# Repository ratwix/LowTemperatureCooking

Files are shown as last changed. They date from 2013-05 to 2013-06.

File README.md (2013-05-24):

LowTemperatureCooking
=====================

Low temperature cooking

Target of this project is to create a Low temperature cooker based on Arduino Teensy 3.

Goal is to heat water to a specific temperature just perfect for cooking the specific dish.
A big amount a pre-set temperature are embeded.

All the temperatures and time cooking comes from "Modernist Cuisine" book.

Main element :
- Teensy3 for main program
- Nokia 5110 for the screen
- DS18B20 for temperature checking
- Rotary encoder to navigate throw menu
- Two button
-- Back / Reset Timer
-- Menu / Validate
- 220V Heat resistor

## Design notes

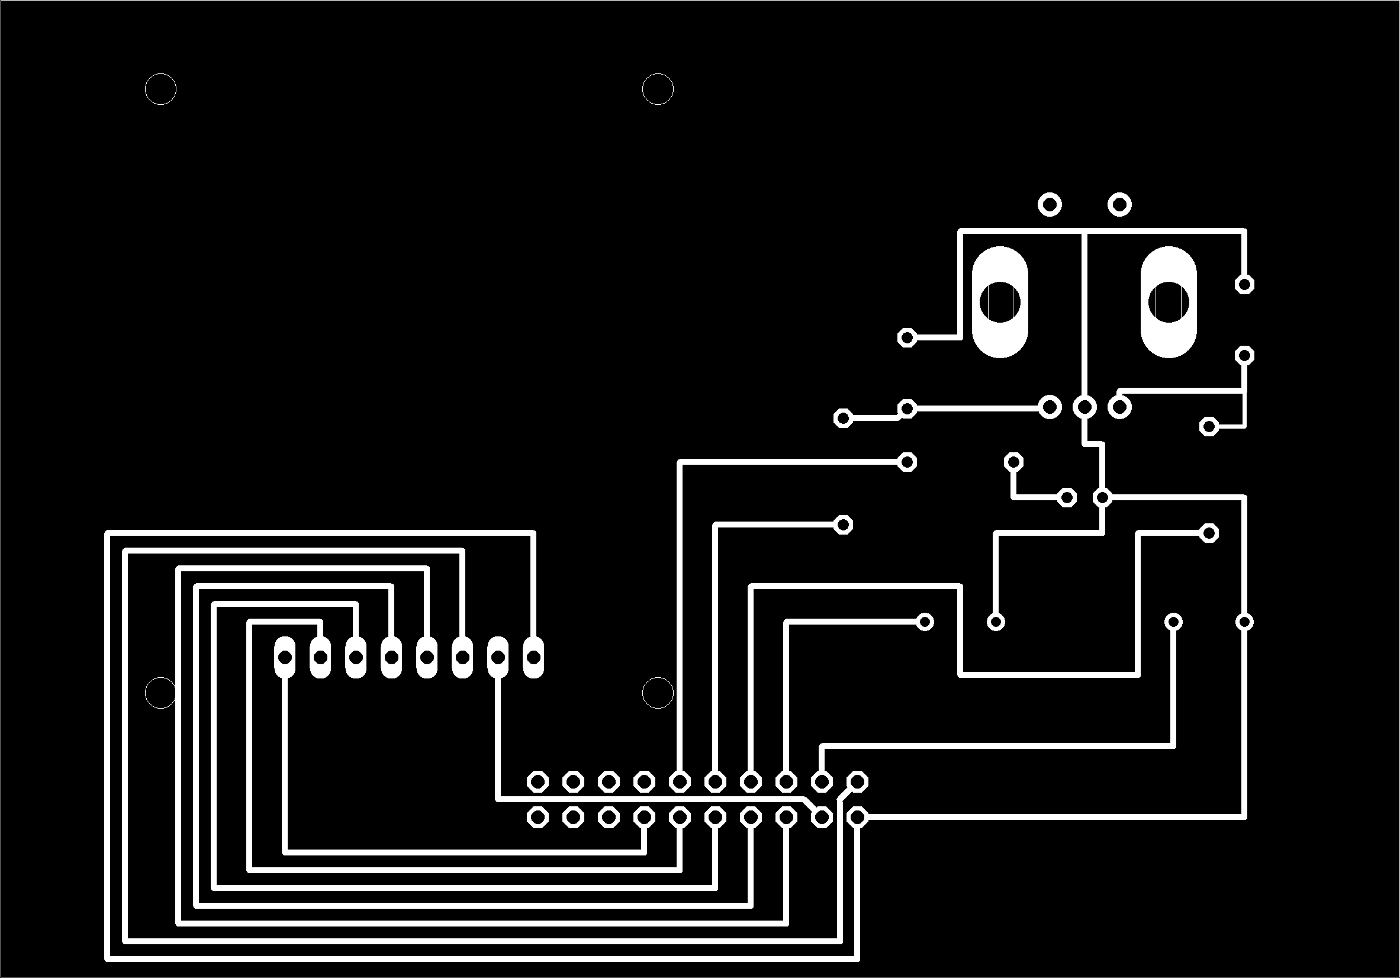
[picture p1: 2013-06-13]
Schematic/CoolCook/board2.png

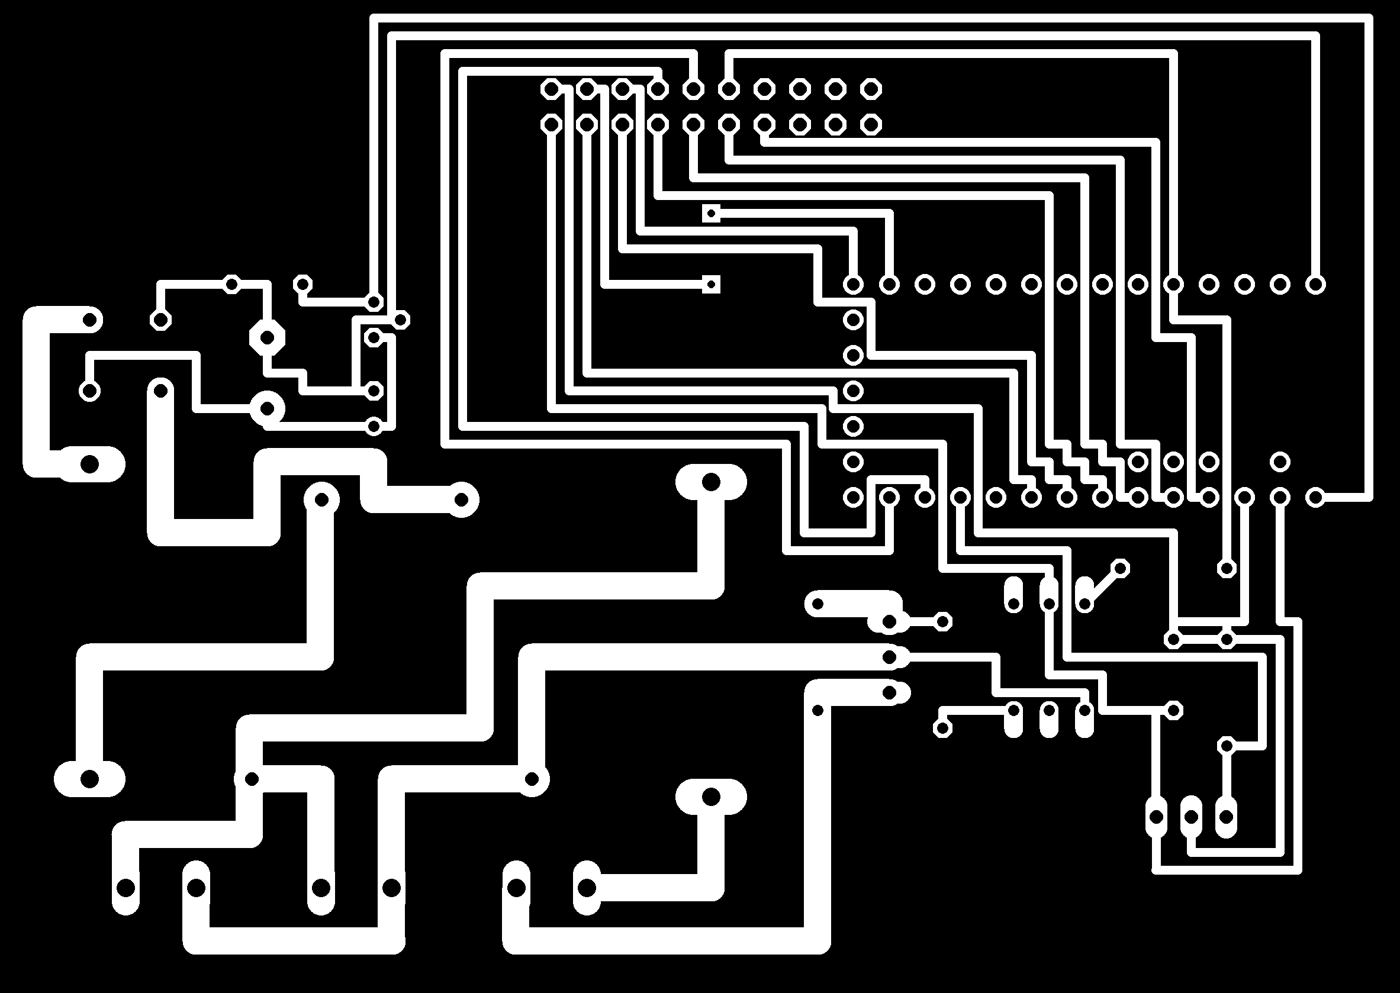
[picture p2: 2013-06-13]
Schematic/CoolCook/board1.png

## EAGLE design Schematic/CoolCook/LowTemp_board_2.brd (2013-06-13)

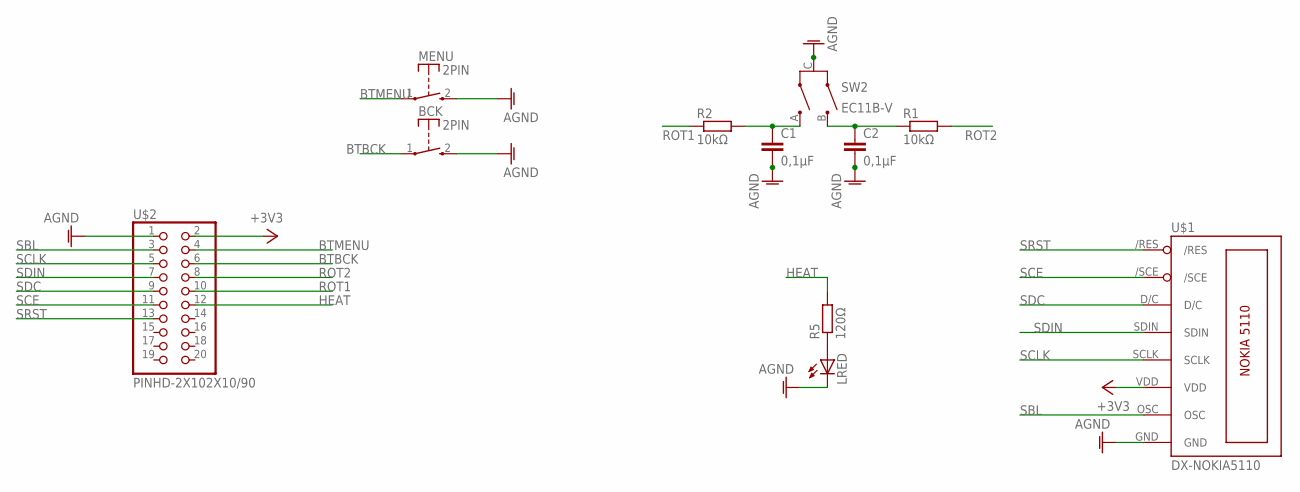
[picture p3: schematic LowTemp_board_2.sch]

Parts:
BCK: 2PIN
C1, C2: 0,1µF; C050-025X075
LRED: LED5MM
MENU: 2PIN
R1, R2: 10kΩ; 0207/7
R5: 120Ω; 0207/7
SW2: EC11B-V
U$1: DX-NOKIA5110
U$2: PINHD-2X102X10/90; 2X10/90

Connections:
+3V3: U$1.VDD, U$2.2
AGND: BCK.2 (S), C1.2, C2.2, LRED.K (C), MENU.2 (S), SW2.C, U$1.GND, U$2.1
BTBCK: BCK.1, U$2.6
BTMENU: MENU.1, U$2.4
HEAT: R5.2, U$2.12
unnamed: C1.1, R2.2, SW2.A
unnamed: C2.1, R1.1, SW2.B
unnamed: LRED.A, R5.1
ROT1: R2.1, U$2.10
ROT2: R1.2, U$2.8
SBL: U$1.OSC, U$2.3
SCE: U$1./SCE, U$2.11
SCLK: U$1.SCLK, U$2.5
SDC: U$1.D/C, U$2.9
SDIN: U$1.SDIN, U$2.7
SRST: U$1./RES, U$2.13

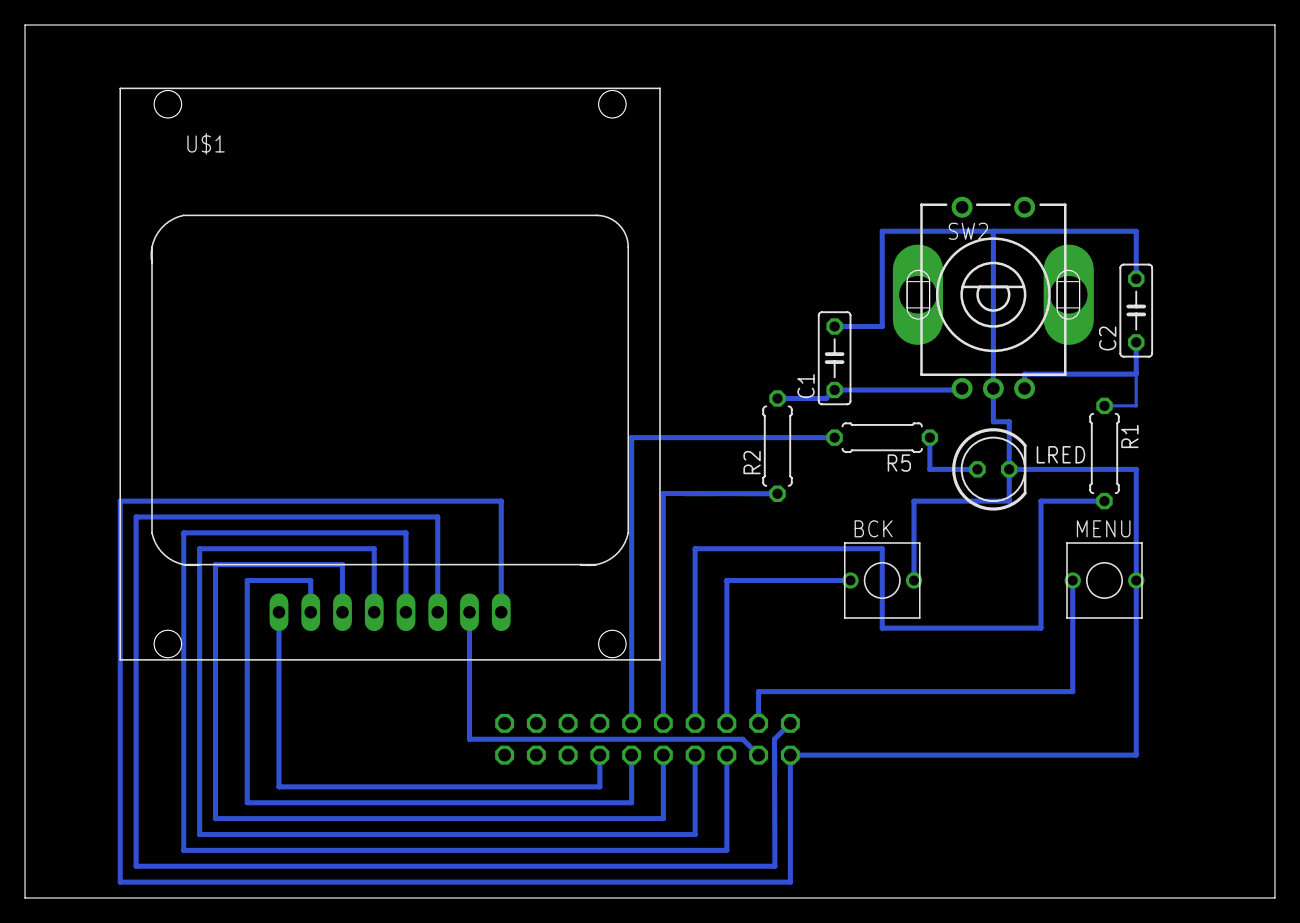
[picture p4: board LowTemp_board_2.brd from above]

Board: 2 copper layers, 100.0 x 69.8 mm, 11 parts (1 on the bottom side), 16 nets.

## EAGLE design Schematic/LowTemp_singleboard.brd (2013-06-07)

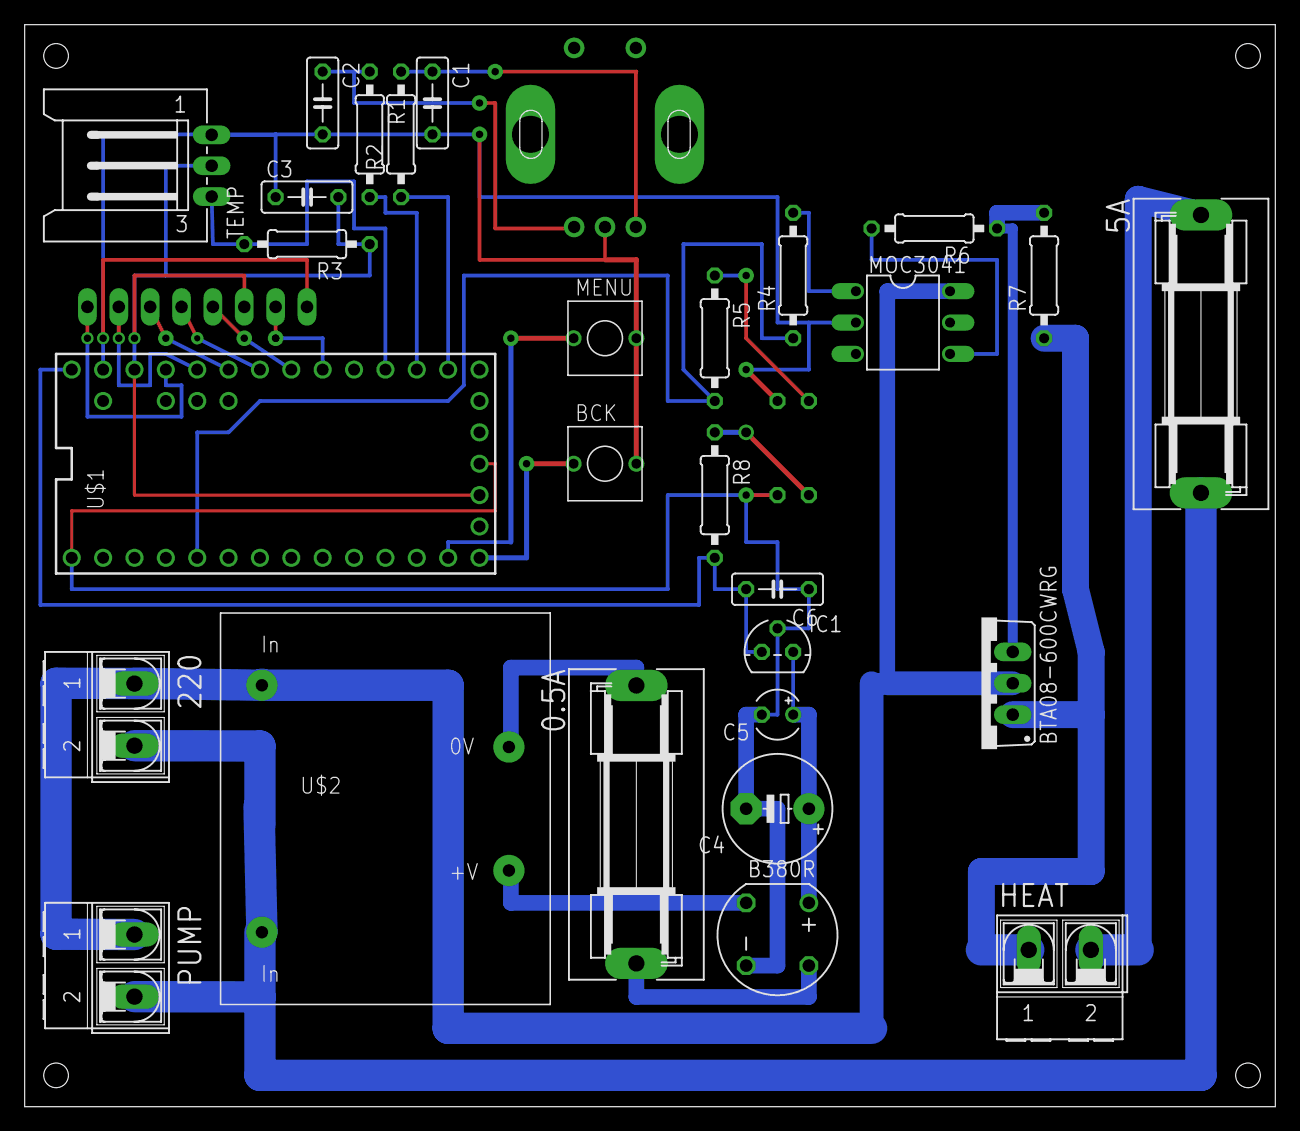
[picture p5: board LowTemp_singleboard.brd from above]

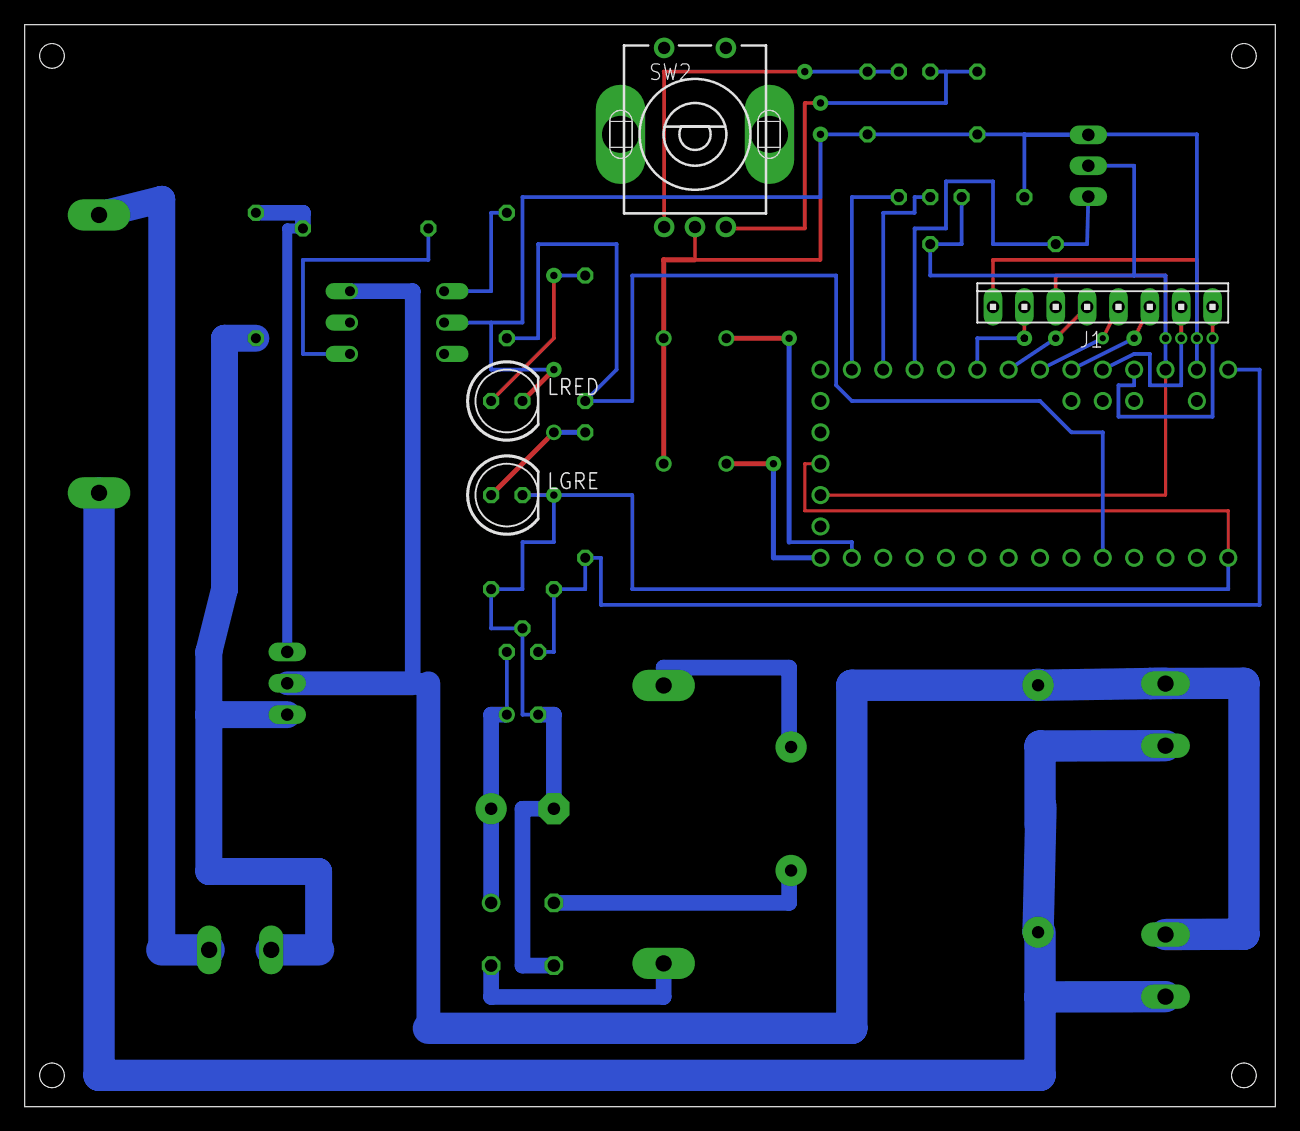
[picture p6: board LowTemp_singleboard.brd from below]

Board: 2 copper layers, 101.3 x 87.6 mm, 32 parts (4 on the bottom side), 31 nets.

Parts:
0.5A, 5A: SH22,5A
220: AK500/2-H
B380R: RB1A
BCK: 2PIN
BTA08-600CWRG: BT138-V; TO220BV
C1, C2, C3, C6: 0,1µF; C050-025X075
C4: 470µF; E5-8,5
C5: 3,3µF; TT2D4
HEAT: AK500/2-H
IC1: 7805L; TO92
J1: SCREEN; 10X08MTA
LGRE: LED5MM
LRED: LED5MM
MENU: 2PIN
MOC3041: MOC3021M; DIL06
PUMP: AK500/2-H
R1, R2: 10kΩ; 0207/10
R3: 47kΩ; 0207/10
R4: 130Ω; 0207/10
R5: 120Ω; 0207/10
R6: 360Ω; 0207/10
R7: 63Ω; 0207/10
R8: 330Ω; 0207/10
SW2: EC11B-V
TEMP: L03P
U$1: TEENSY_3.0+4
U$2: 1

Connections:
220VA: BTA08-600CWRG.T2, MOC3041.6, PUMP.1, U$2.1
220VC: 5A.2, 220.2, PUMP.2, U$2.5
+3V3: C3.2, J1.6, R3.1, TEMP.2, U$1.3.3V, U$1.3.3V1
+5V: C6.2, IC1.1, R8.2, U$1.VIN
AGND: BCK.2, C1.2, C2.2, C3.1, J1.8, LRED.K, MENU.2, MOC3041.2, SW2.C, TEMP.1, U$1.AGND
BTBCK: BCK.1, U$1.12
BTMENU: MENU.1, U$1.11
GND: B380R.-, C4.-, C5.-, C6.1, IC1.2, LGRE.K, U$1.GND, U$1.GND1
HEAT: R4.1, R5.2, U$1.3
unnamed: C1.1, R2.2, SW2.A
unnamed: C2.1, R1.1, SW2.B
unnamed: MOC3041.1, R4.2
unnamed: LRED.A, R5.1
unnamed: MOC3041.4, R6.2
unnamed: BTA08-600CWRG.G, R6.1, R7.2
unnamed: 0.5A.1, U$2.9
unnamed: BTA08-600CWRG.T1, HEAT.1, R7.1
unnamed: 5A.1, HEAT.2
unnamed: B380R.AC2, U$2.7
unnamed: 0.5A.2, B380R.AC1
unnamed: B380R.+, C4.+, C5.+, IC1.3
unnamed: LGRE.A, R8.1
ROT1: R2.1, U$1.14/A0
ROT2: R1.2, U$1.15/A1
SBL: J1.7, U$1.18/A4
SCE: J1.2, U$1.22/A8
SCLK: J1.5, U$1.19/A5
SDC: J1.3, U$1.21/A7
SDIN: J1.4, U$1.20/A6
SRST: J1.1, U$1.23/A9
TEMP: R3.2, TEMP.3, U$1.16/A2

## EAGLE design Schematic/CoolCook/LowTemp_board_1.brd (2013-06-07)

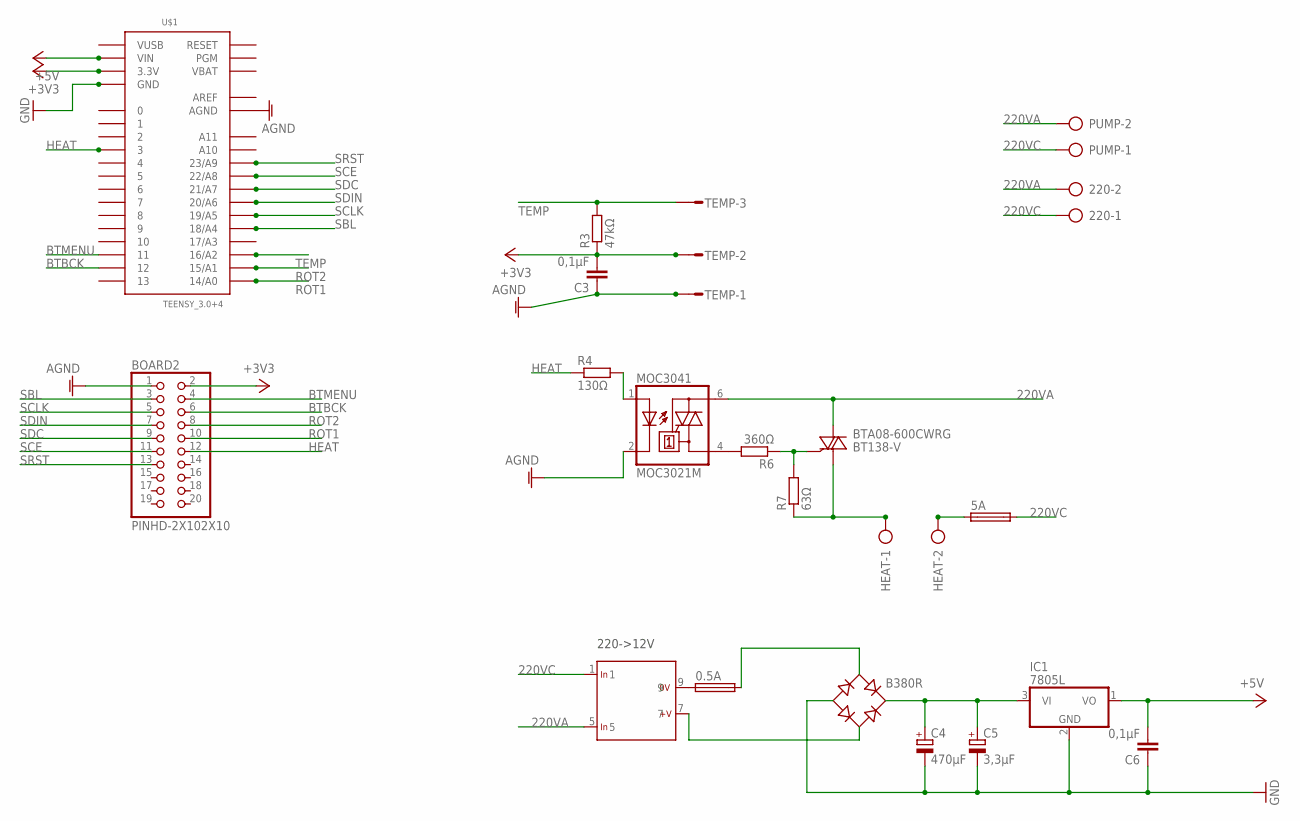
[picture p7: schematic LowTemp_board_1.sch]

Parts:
0.5A, 5A: SH22,5A
220: AK500/2-H
220->12V: SINGLE; 1
B380R: RB1A
BOARD2: PINHD-2X102X10; 2X10
BTA08-600CWRG: BT138-V; TO220BV
C3, C6: 0,1µF; C050-025X075
C4: 470µF; E5-8,5
C5: 3,3µF; TT2D4
HEAT: AK500/2-H
IC1: 7805L; TO92
MOC3041: MOC3021M; DIL06
PUMP: AK500/2-H
R3: 47kΩ; 0207/7
R4: 130Ω; 0207/7
R6: 360Ω; 0207/7
R7: 63Ω; 0207/7
TEMP: S03P
U$1: TEENSY_3.0+4

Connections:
220VA: 220.2, 220->12V.5, BTA08-600CWRG.T2 (A2), MOC3041.6 (A2), PUMP.2
220VC: 5A.2, 220.1, 220->12V.1, PUMP.1
+3V3: BOARD2.2, C3.2, R3.1, TEMP.2, U$1.3.3V, U$1.3.3V1 (3.3V)
+5V: C6.2, IC1.1 (VO), U$1.VIN
AGND: BOARD2.1, C3.1, MOC3041.2 (C), TEMP.1, U$1.AGND
AREF: U$1.AREF
BTBCK: BOARD2.6, U$1.12
BTMENU: BOARD2.4, U$1.11
GND: B380R.-, C4.-, C5.-, C6.1, IC1.2 (GND), U$1.GND, U$1.GND1 (GND)
HEAT: BOARD2.12, R4.1, U$1.3
unnamed: MOC3041.1 (A), R4.2
unnamed: MOC3041.4 (A1), R6.2
unnamed: BTA08-600CWRG.G, R6.1, R7.2
unnamed: 0.5A.1, 220->12V.9
unnamed: BTA08-600CWRG.T1 (A1), HEAT.1, R7.1
unnamed: 5A.1, HEAT.2
unnamed: 220->12V.7, B380R.AC2
unnamed: 0.5A.2, B380R.AC1
unnamed: B380R.+, C4.+, C5.+, IC1.3 (VI)
ROT1: BOARD2.10, U$1.14/A0
ROT2: BOARD2.8, U$1.15/A1
SBL: BOARD2.3, U$1.18/A4
SCE: BOARD2.11, U$1.22/A8
SCLK: BOARD2.5, U$1.19/A5
SDC: BOARD2.9, U$1.21/A7
SDIN: BOARD2.7, U$1.20/A6
SRST: BOARD2.13, U$1.23/A9
TEMP: R3.2, TEMP.3, U$1.16/A2
VBAT: U$1.VBAT
VUSB: U$1.VUSB

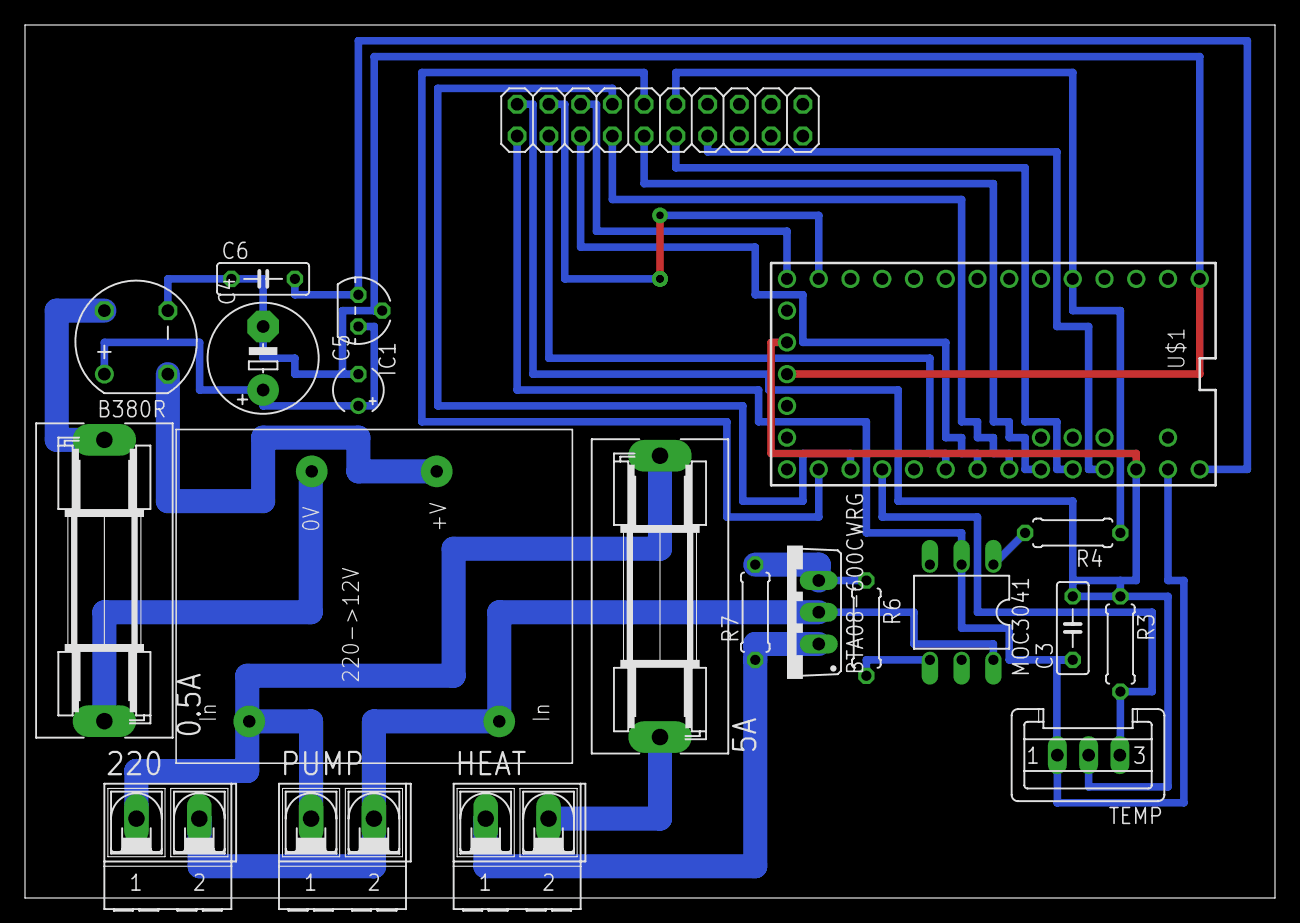
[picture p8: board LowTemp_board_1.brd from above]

Board: 2 copper layers, 100.0 x 69.8 mm, 21 parts (0 on the bottom side), 27 nets.

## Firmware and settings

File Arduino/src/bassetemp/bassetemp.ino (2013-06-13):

#include <OneWire.h> // Inclusion de la librairie OneWire
#include <Time.h>
#define ENCODER_OPTIMIZE_INTERRUPTS //Rotary optimization
#include <Encoder.h> //Rotary encoder
#include <Bounce.h> //Button management
#include <Adafruit_GFX.h>
#include <Adafruit_PCD8544.h>

#include "logo.h"
#include "menu.h"

/**
  *  Ecran
  */

#define DELAY_REFRESH_TEMP  100

#define PIN_SCREEN_LED    18
#define PIN_SCREEN_SCLK   19
#define PIN_SCREEN_DIN    20
#define PIN_SCREEN_DC     21
#define PIN_SCREEN_CS     22
#define PIN_SCREEN_RST    23
#define DELAY_REFRESH_SCREEN  100
#define DELAY_MENU_TIMEOUT    20000
#define DELAY_SCROLL          200
#define DELAY_SCROLL_DELAY    4

Adafruit_PCD8544 display = Adafruit_PCD8544(PIN_SCREEN_SCLK, PIN_SCREEN_DIN, PIN_SCREEN_DC, PIN_SCREEN_CS, PIN_SCREEN_RST);

elapsedMillis time_refreshTemperature;
elapsedMillis time_refreshScreen;
elapsedMillis time_menuTimeout;
elapsedMillis time_menuScroll;

int scroll_poss = 0;
int scroll_max = 0;

/**
  * Temperature
  */

#define DS18B20     0x28     // Adresse 1-Wire du DS18B20
#define PIN_DS18B20 16       // Pin used for temp 1-Wire
#define PIN_HEAT    3        // Pin connected to HEAT system (PWM)

OneWire ds(PIN_DS18B20);

float   g_target_temp   = 40.0;
float   g_current_temp  = 12.4;

boolean  g_heat = false; //Heat if true

/**
  * Chronometre
  */
  
time_t g_chrono_time = now();

/**
  * Rotary Encoder
  */
#define PIN_ROTARY1         15
#define PIN_ROTARY2         14
#define ENCODER_STEP        0.1 //Add 0.1° each step
#define ENCODER_MENU_STEP   2   //Increment menu each 2 tick
Encoder g_rotaryEncoder(PIN_ROTARY1, PIN_ROTARY2);

/**
  * Button
  */
  
#define  PIN_BUTTON_RESET_TIMER  12
#define  PIN_BUTTON_MENU         11

Bounce buttonResetTimer = Bounce(PIN_BUTTON_RESET_TIMER, 10);
Bounce buttonMenu = Bounce(PIN_BUTTON_MENU, 10);

/************************************************************************************
  ******
  ******  Main loop
  ******
  ***********************************************************************************/

void setup()   {
  Serial.begin(9600);
  
  pinMode(PIN_HEAT, OUTPUT);
  
  pinMode(PIN_BUTTON_RESET_TIMER, INPUT_PULLUP);
  pinMode(PIN_BUTTON_MENU, INPUT_PULLUP);

  //Switch screen led on
  pinMode(PIN_SCREEN_LED, OUTPUT);
  
  digitalWrite(PIN_SCREEN_LED, HIGH);
  
  //Initialise Screen
  display.begin();
  display.setContrast(51);

  //display.display(); // show splashscreen
  display.clearDisplay();
  //display.command(PCD8544_DISPLAYCONTROL | PCD8544_DISPLAYNORMAL);
  display.drawBitmap(0, 0, logo, logox, logoy, BLACK);
  display.display();
  delay(3000);
  display.clearDisplay();   // clears the screen and buffer
  display.setTextWrap(false); // Do not wrap text (for scrolling effect)
  
  g_rotaryEncoder.write(0);
  

}

void loop() {
  testControl();
  refreshTemp();
  refreshScreen();
  menuTimeout();
}

/************************************************************************************
  ******
  ******  Control management
  ******
  ***********************************************************************************/

/**
 * Test all controls
 */

void testControl() {
  testButtonReset();
  testButtonMenu();
  readRotaryEncoder();
}

/**
 * Test Reset / Back button
 */

void testButtonReset() {
  if (buttonResetTimer.update()) {
     if (buttonResetTimer.fallingEdge()) {
        time_menuTimeout = 0;
        scroll_poss = DELAY_SCROLL_DELAY;
        if (g_current_menu == 0) {
          g_chrono_time = now();
        } else if (g_current_menu == 1) {
          g_current_menu = 0;
        } else if (g_current_menu == 2) {
          g_current_menu = 1;
        } else if (g_current_menu == 3) {
          g_current_menu = 2;
        } else {
          g_current_menu = 0;
        }
     } 
  }
}

/**
  * Test Menu / Validate button
  */
  
void testButtonMenu() {
  if (buttonMenu.update()) {
     if (buttonMenu.fallingEdge()) {
        time_menuTimeout = 0;
        scroll_poss = DELAY_SCROLL_DELAY;
        if (g_current_menu == 0) {
           init_menu(); //Put current menu item at 0
           g_current_menu = 1; 
        } else if (g_current_menu == 1) { //Goto menu 2
           g_current_menu_2 = 0;
           g_current_menu_3 = 0;
           g_current_menu = 2; 
        } else if (g_current_menu == 2) { //Goto menu 3
           g_current_menu_3 = 0;
           g_current_menu = 3; 
        } else if (g_current_menu == 3) { //Assign temperature
           char tmp = temperature[g_current_menu_1].menu2[g_current_menu_2].menu3[g_current_menu_3].temp;
           if (tmp > 0) {
               g_target_temp = tmp + 1;
           }
           g_current_menu = 0; 
        } else {
           g_current_menu = 0; 
        }
     } 
  }
}

/**
  * Read roatry encoder (left / right
  * If main screen : change target temperature
  * If menu : navigate throw items
  */

void readRotaryEncoder() {
  static int nbTic = 0;
  long newPosition = g_rotaryEncoder.read();
  
  if (newPosition != 0) {
      time_menuTimeout = 0;
      scroll_poss = DELAY_SCROLL_DELAY;
      if (g_current_menu == 0) { //In main screen, directly change temperature
        g_target_temp += newPosition * ENCODER_STEP;
      } else  { //Navigate throw menu
        nbTic += newPosition;
        if (nbTic % ENCODER_MENU_STEP == 0) { //Increment calculator
           if (g_current_menu == 1) {
             int menu_size = get_menu1_size();
             g_current_menu_1 += nbTic > 0 ? 1 : -1; //Increment menu
             if (g_current_menu_1 < 0) { g_current_menu_1 = 0; } //manage menu size
             if (g_current_menu_1 >= menu_size) { g_current_menu_1 = menu_size - 1; }
           } else if (g_current_menu == 2) { 
             int menu_size = get_menu2_size(g_current_menu_1);
             g_current_menu_2 += nbTic > 0 ? 1 : -1; //Increment menu
             if (g_current_menu_2 < 0) { g_current_menu_2 = 0; } //manage menu size
             if (g_current_menu_2 >= menu_size) { g_current_menu_2 = menu_size - 1; }
           } else if (g_current_menu == 3) {
             int menu_size = get_menu3_size(g_current_menu_1, g_current_menu_2);
             g_current_menu_3 += nbTic > 0 ? 1 : -1; //Increment menu
             if (g_current_menu_3 < 0) { g_current_menu_3 = 0; } //manage menu size
             if (g_current_menu_3 >= menu_size) { g_current_menu_3 = menu_size - 1; }
           }
           nbTic = 0; 
        }
      }
      g_rotaryEncoder.write(0);  
  }
}



/************************************************************************************
  ******
  ******  Temperature capture management
  ******
  ***********************************************************************************/

/**
  * Read Temperature.
  * If temperature < target, heat, else stno
  */

void refreshTemp() {
  if (time_refreshTemperature > DELAY_REFRESH_TEMP) {
      time_refreshTemperature -= DELAY_REFRESH_TEMP;
      getTemperature(&g_current_temp);
      if (g_current_temp < g_target_temp) {
        digitalWrite(PIN_HEAT, HIGH);        //TURN HEAT ON
      } else {
        digitalWrite(PIN_HEAT, LOW);         //TURN HEAT OFF
      }
  }
}

/**
  * Get current temperature in Celcius
  */

boolean getTemperature(float *temp){
  byte data[9], addr[8];
  // data : Données lues depuis le scratchpad
  // addr : adresse du module 1-Wire détecté
  

  if (!ds.search(addr)) { // Recherche un module 1-Wire
    ds.reset_search();    // Réinitialise la recherche de module
    return false;         // Retourne une erreur
  }
  
  if (OneWire::crc8(addr, 7) != addr[7]) // Vérifie que l'adresse a été correctement reçue
    return false;                        // Si le message est corrompu on retourne une erreur

  if (addr[0] != DS18B20) // Vérifie qu'il s'agit bien d'un DS18B20
    return false;         // Si ce n'est pas le cas on retourne une erreur

  ds.reset();             // On reset le bus 1-Wire
  ds.select(addr);        // On sélectionne le DS18B20
  
  ds.write(0x44, 1);      // On lance une prise de mesure de température
  //delay(400);             // Et on attend la fin de la mesure
  
  ds.reset();             // On reset le bus 1-Wire
  ds.select(addr);        // On sélectionne le DS18B20
  ds.write(0xBE);         // On envoie une demande de lecture du scratchpad

  for (byte i = 0; i < 9; i++) // On lit le scratchpad
    data[i] = ds.read();       // Et on stock les octets reçus
  
  // Calcul de la température en degré Celsius
  *temp = ((data[1] << 8) | data[0]) * 0.0625; 
  
  // Pas d'erreur
  return true;
}

/************************************************************************************
  ******
  ******  SCREEN MANAGEMENT
  ******
  ***********************************************************************************/

/**
 * Choose what to display on screen
 */

void refreshScreen() {
  menuScroll(); 
  if (time_refreshScreen > DELAY_REFRESH_SCREEN) {
       time_refreshScreen -= DELAY_REFRESH_SCREEN;
       
       if (g_current_menu == 1) { //On est dans le premier menu : choix du type d'ingrédient
         screen_display_menu1();
       } else if (g_current_menu == 2) { //On est dans le premier menu : choix du type d'ingrédient
         screen_display_menu2();
       } else if (g_current_menu == 3) { //On est dans le premier menu : choix du type d'ingrédient
         screen_display_menu3();
       } else {
         screen_display_temp();
       }
   }
}

void menuTimeout() {
   if (time_menuTimeout > DELAY_MENU_TIMEOUT) {
      time_menuTimeout = 0;
      g_current_menu = 0;
  }
}

void menuScroll() {
    if (time_menuScroll > DELAY_SCROLL) {
      time_menuScroll -= DELAY_SCROLL;
      scroll_poss--;
      if (scroll_poss < scroll_max) {
          scroll_poss = DELAY_SCROLL_DELAY;
      }
  }
}

int getMenuScroll() {
  return scroll_poss > 0 ? 0 : scroll_poss;
}

/**
  * Display temperature screen
  */
  
void screen_display_temp() {
  char target_temp[5];
  char current_temp[5];
  time_t currentTime = now() - g_chrono_time; //Le chrono actuel
  char chrono[8];
  
  
  sprintf(chrono, "%02d:%02d:%02d", hour(currentTime), minute(currentTime), second(currentTime));
  sprintf(target_temp, "%.1f", g_target_temp); //Display target temperature
  sprintf(current_temp, "%.1f", g_current_temp); //Display current temperature
  

  display.clearDisplay();
  display.setTextColor(BLACK);
  display.setCursor(0,0);
  //Display elapse time
  display.setTextSize(1);
  display.println(chrono);
  //Display Target temperature
  display.setTextSize(2);
  display.println(target_temp);
  //Display current temperature
  display.setTextSize(3);
  display.println(current_temp);
  display.display();
}

void scroll_text(const char* label) {
  int label_size = 0;
  while (label[label_size] != '\0') {
      label_size++;
  }
  Serial.print(label_size);
  Serial.print(':');
  if (label_size > SCREEN_NB_COLUMN_MENU) {
    scroll_max = -((label_size - SCREEN_NB_COLUMN_MENU) * (SCREEN_CHAR_LENGTH + 2));
    Serial.print(getMenuScroll());
    Serial.print(':');
    Serial.println(scroll_max);
    display.setCursor(display.getCursorX() + getMenuScroll(), display.getCursorY());
  }  
}

/**
  * Display menu 1 : Dish type
  */
void screen_display_menu1() {
    int menu_size = get_menu1_size();
    int start_item;
    int end_item;
    display.clearDisplay();
    display.setCursor(0,0);
    display.setTextSize(1);
    
    // Select start & end elements
    if (menu_size <= SCREEN_NB_LINE_MENU) {
      start_item = 0;
      end_item = menu_size;
    } else {
      start_item = g_current_menu_1 - (SCREEN_NB_LINE_MENU / 2 - 1);
      if (start_item < 0) {
        start_item = 0;
      }
      
      end_item = start_item + SCREEN_NB_LINE_MENU;
      if (end_item > menu_size) {
         start_item -= end_item - menu_size;
         end_item = menu_size;
      }
    }
    
    //Display items
    for (int i = start_item; i < end_item; i++) {
      if (i == g_current_menu_1) { //If select item, highlight it
          display.setTextColor(WHITE, BLACK);
          scroll_text(temperature[i].label);
        } else {
          display.setTextColor(BLACK);
        }
        display.println(temperature[i].label); 
    }
    
    //Display target temp
    
    display.display();
}

/**
  * Display menu 2 : Dish
  */
void screen_display_menu2() {
    int menu_size = get_menu2_size(g_current_menu_1);
    int start_item;
    int end_item;
    
    display.clearDisplay();
    display.setCursor(0,0);
    display.setTextSize(1);
    
    // Select start & end elements
    if (menu_size <= SCREEN_NB_LINE_MENU) {
      start_item = 0;
      end_item = menu_size;
    } else {
      start_item = g_current_menu_2 - (SCREEN_NB_LINE_MENU / 2 - 1);
      if (start_item < 0) {
        start_item = 0;
      }
      
      end_item = start_item + SCREEN_NB_LINE_MENU;
      if (end_item > menu_size) {
         start_item -= end_item - menu_size;
         end_item = menu_size;
      }
    }
    
    for (int i = start_item; i < end_item; i++) {
      if (i == g_current_menu_2) { //If select item, highlight it
          display.setTextColor(WHITE, BLACK);
          scroll_text(temperature[g_current_menu_1].menu2[i].label);
        } else {
          display.setTextColor(BLACK);
        }
        display.println(temperature[g_current_menu_1].menu2[i].label);
    }
    
    display.display();
}

/**
  * Display menu 4 : Cook
  */
void screen_display_menu3() {
int menu_size = get_menu3_size(g_current_menu_1, g_current_menu_2);
    display.clearDisplay();
    display.setCursor(0,0);
    display.setTextSize(1);
    
    int start_item;
    int end_item;
    
    // Select start & end elements
    if (menu_size <= SCREEN_NB_LINE_MENU) {
      start_item = 0;
      end_item = menu_size;
    } else {
      start_item = g_current_menu_3 - (SCREEN_NB_LINE_MENU / 2 - 1);
      if (start_item < 0) {
        start_item = 0;
      }
      
      end_item = menu_size > SCREEN_NB_LINE_MENU ? start_item + SCREEN_NB_LINE_MENU : menu_size;
      if (end_item > menu_size) {
         start_item -= end_item - menu_size;
         end_item = menu_size;
      }
    }
    //Display item
    for (int i = start_item; i < end_item; i++) {
      if (i == g_current_menu_3) { //If select item, highlight it
          display.setTextColor(WHITE, BLACK);
          scroll_text(temperature[g_current_menu_1].menu2[g_current_menu_2].menu3[i].label);
        } else {
          display.setTextColor(BLACK);
        }
        if (temperature[g_current_menu_1].menu2[g_current_menu_2].menu3[i].suggest) {
          display.print(temperature[g_current_menu_1].menu2[g_current_menu_2].menu3[i].label);
          display.println("*"); //Add a * for favorite cooking
        } else {
          display.println(temperature[g_current_menu_1].menu2[g_current_menu_2].menu3[i].label);
        }
    }
    //Display target temp
    char t[4];
    sprintf(t, "%02dC", temperature[g_current_menu_1].menu2[g_current_menu_2].menu3[g_current_menu_3].temp);
    display.setCursor(45,33);
    display.setTextColor(BLACK);
    display.setTextSize(2);
    display.println(t);
    //Display cooking time
    int m = temperature[g_current_menu_1].menu2[g_current_menu_2].menu3[g_current_menu_3].minutes;
    if (m != 0) {
      char t2[8];
      int tm = m % 60;
      int th = m / 60;
      
      if (th > 0) {
        if (tm > 0) {
          sprintf(t2, "%dh%dm", th, tm); 
        } else {
          sprintf(t2, "%dh", th); 
        }
      } else {
        sprintf(t2, "%dmin", tm); 
      }
      display.setCursor(0, 40);
      display.setTextSize(1);
      display.print(t2);
    }
    
    
    display.display();
}

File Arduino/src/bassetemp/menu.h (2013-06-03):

#ifndef _TEMPERATURE_H_
#define _TEMPERATURE_H_

#define MAX_MENU1  8
#define MAX_MENU2  23
#define MAX_MENU3  4

#define SCREEN_NB_LINE_MENU    6    //Display max 6 lines
#define SCREEN_NB_COLUMN_MENU  14   //Display max 14 columns
#define SCREEN_CHAR_LENGTH  6   //Display max 14 columns

char g_current_menu = 0;
int g_current_menu_1 = 0;
int g_current_menu_2 = 0;
int g_current_menu_3 = 0;

typedef struct {
  char                label[14];  //dish
  char                temp;       //target temperature
  boolean             suggest;    //Best cooking
  int                 minutes;
} s_menu_3;  
typedef struct  {
  char         label[20];
  s_menu_3     menu3[MAX_MENU3];
} s_menu_2;

typedef struct  { //First menu level
   char        label[17];
   s_menu_2    menu2[MAX_MENU2]; //Max nb menu 2
} s_menu_1;

static const s_menu_1  temperature[] = 
  {
    {"Viande Tendre", {
                  {"Agneau Carre", 
                    {
                      {"Saignant", 54, false},
                      {"A point",  57, true},
                      {"Rose",  59, true},
                      {"Cuit", 62, false}
                    }
                  },
                  {"Agneau Gigot", 
                    {
                      {"Saignant", 54, false},
                      {"A point",  57, false},
                      {"Rose",  60, true},
                      {"Cuit", 65, false}
                    }
                  },
                  {"Boeuf Aloyau", 
                    {
                      {"Saignant", 52, false},
                      {"A point",  54, true},
                      {"Rose",  58, false},
                      {"Cuit", 60, false}
                    }
                  },
                  {"Boeuf Cotes", 
                    {
                      {"Saignant", 54, false},
                      {"A point",  56, true},
                      {"Rose",  58, false},
                      {"Cuit", 60, false}
                    }
                  },
                  {"Boeuf Filet Mignon", 
                    {
                      {"Saignant", 50, true},
                      {"A point",  53, false},
                      {"Rose",  56, false},
                      {"Cuit", 62, false}
                    }
                  },
                  {"Boeuf Flanche", 
                    {
                      {"Saignant", 54, false},
                      {"A point",  56, true},
                      {"Rose",  59, false},
                      {"Cuit", 62, false}
                    }
                  },
                  {"Boeuf Onglet", 
                    {
                      {"Saignant", 51, false},
                      {"A point",  54, false},
                      {"Rose",  58, true},
                      {"Cuit", 60, false}
                    }
                  },
                  {"Chevreuil Longue", 
                    {
                      {"Saignant", 50, true},
                      {"A point",  53, true},
                      {"Rose",  58, false},
                      {"Cuit", 60, false}
                    }
                  },
                  {"Cochon de lait", 
                    {
                      {"A point",  56, true},
                      {"Rose",  58, true},
                      {"Cuit", 60, true}
                    }
                  },
                  {"Lapin Filet", 
                    {
                      {"A point",  56, false},
                      {"Rose",  59, true},
                      {"Cuit", 62, false}
                    }
                  },
                  {"Porc Filet", 
                    {
                      {"A point",  56, false},
                      {"Rose",  59, true},
                      {"Cuit", 61, false}
                    }
                  },
                  {"Porc Longe", 
                    {
                      {"A point",  58, false},
                      {"Rose",  60, true},
                      {"Cuit", 62, false}
                    }
                  },
                  {"Porc Palette", 
                    {
                      {"A point",  58, false},
                      {"Rose",  60, true},
                      {"Cuit", 64, false}
                    }
                  },
                  {"Veau Longe", 
                    {
                      {"Saignant", 52, true},
                      {"A point",  54, true},
                      {"Rose",  56, true},
                      {"Cuit", 60, true}
                    }
                  }
                }
    },
    {"Viande Ferme", {
                        {"Agneau epaule", 
                          {
                            {"Ferme (steak)", 56, true, 48 * 60},
                            {"Tendre souple",  62, false, 48 * 60},
                            {"Tendre defait",  65, true, 24  * 60},
                            {"Tres defait",  85, false, 5 * 60}
                          }
                        },
                        {"Agneau jaret", 
                          {
                            {"Ferme (steak)", 58, false, 48 * 60},
                            {"Tendre souple",  62, true, 48 * 60},
                            {"Tendre defait",  85, false, 5  * 60},
                            {"Tres defait",  88, false, 5 * 60}
                          }
                        },
                        {"Boeuf bavette", 
                          {
                            {"Ferme (steak)", 50, false, 3 * 60},
                            {"Tendre souple",  55, true, 12 * 60},
                            {"Tendre defait",  62, false, 36  * 60},
                            {"Tres defait",  88, false, 7 * 60}
                          }
                        },
                        {"Boeuf cotes avec os", 
                          {
                            {"Ferme (steak)", 56, false, 72 * 60},
                            {"Tendre souple",  58, false, 72 * 60},
                            {"Tendre defait",  60, true, 72  * 60},
                            {"Tres defait",  88, false, 7 * 60}
                          }
                        },
                        {"Boeuf joue", 
                          {
                            {"Ferme (steak)", 58, false, 72 * 60},
                            {"Tendre souple",  62, true, 72 * 60},
                            {"Tendre defait",  68, false, 36  * 60},
                            {"Tres defait",  80, false, 12 * 60}
                          }
                        },
                        {"Boeuf onglet", 
                          {
                            {"Ferme (steak)", 50, true, 2 * 60},
                            {"Tendre souple",  55, false, 12 * 60},
                            {"Tendre defait",  62, false, 36  * 60},
                            {"Tres defait",  88, false, 6 * 60}
                          }
                        },
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

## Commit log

2013-05-22 First commit Arduino file
2013-05-24 Add scrolling text Rename temperature.h to menu.h Complete menu.h (missing hard meets)
    [bassetemp.ino, menu.h]
2013-05-24 Complete menu.h file with all dish Sort them by alphabetic order (french) Add heat connection on pin 3 (heat when temperature too low)
    [bassetemp.ino, menu.h]
2013-06-03 Optimize Rotary encoder Correct menu.h Add a splashscreen logo
    [bassetemp.ino, menu.h]
2013-06-04 Add Schematics
    [LowTemp.brd, LowTemp.sch]
2013-06-07 Add 2 board schematic. One board for the controls (screen / button) One board for electronics part
    Each board areBoards are connected together with 2x10 pin connector
    [LowTemp_board_1.brd, LowTemp_board_1.sch, LowTemp_board_2.brd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]
2013-06-13 Update schematic in two boards (test and work great) Reverse rotation in arduino program
    [LowTemp_board_2.brd, LowTemp_board_2.sch]
